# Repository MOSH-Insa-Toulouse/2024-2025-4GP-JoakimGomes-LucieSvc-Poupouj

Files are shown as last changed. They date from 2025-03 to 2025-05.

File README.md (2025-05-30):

<!DOCTYPE html>
<html lang="fr">
<head>
  <meta charset="UTF-8">
</head>

<body>

# 2024-2025-4GP-JoakimGomes-LucieSvc-Poupouj
## Développement d'un capteur low-tech à base de Graphite : de la conception au test

### Sommaire
<hr/>
<ul>
<li> <a href="#Introduction">Introduction </a></li>
<li> <a href="#Livrables">Livrables </a></li>
<li> <a href="#Matériel à disposition">Matériel à disposition </a></li>
<li> <a href="#Simulation électronique sur LTSpice">Simulation électronique sur LTSpice </a></li>
<li> <a href="#Design du PCB avec KiCad">Design du PCB avec KiCad </a></li>
<li> <a href="#Réalisation du Shield">Réalisation du Shield </a></li>
<li> <a href="#Développement du code Arduino">Développement du code Arduino </a></li>
<li> <a href="#Développement de l'application mobile APK avec MIT App Inventor">Développement de l'application mobile APK avec MIT App Inventor </a></li>
<li> <a href="#Banc de test">Banc de test </a></li>
<li> <a href="#Datasheet">Datasheet </a></li>
<li> <a href="#Conclusion">Conclusion </a></li>
<li> <a href="#Contact">Contact </a></li>
</ul>

<h2 id="Introduction">Introduction</h2>

<p>L'UF "du capteur au banc de test" a pour objectif de concevoir un capteur low-tech et de pouvoir ensuite le tester afin de le comparer avec un capteur commercial. Le capteur est à base de graphite, que l'on retrouve notamment dans nos crayons à papier. Son développement est issu de l'article scientifique <i>"Pencil Drawn Strain Gauges and Chemiresistors on Paper"</i>(Cheng-Wei Lin*, Zhibo Zhao*, Jaemyung Kim & Jiaxing Huang). Concevoir ce capteur est relativement simple : on applique à l'aide d'un crayon, du graphite sur un morceau de papier. Les couches de graphite déposées sur le papier agissent comme un conducteur électrique qui, lorsqu'on déforme le papier, a une conductivité (et donc une résistance) qui varie. Cela s'explique par le fait que  le nombre de chaînes de particules de graphite connectées varie selon le type de déformation. En tension, il y a moins de chaines et ces dernières sont plus courtes. C'est le contraire en compression avec des chaines plus proches, laissant ainsi mieux passer le courant.</p>

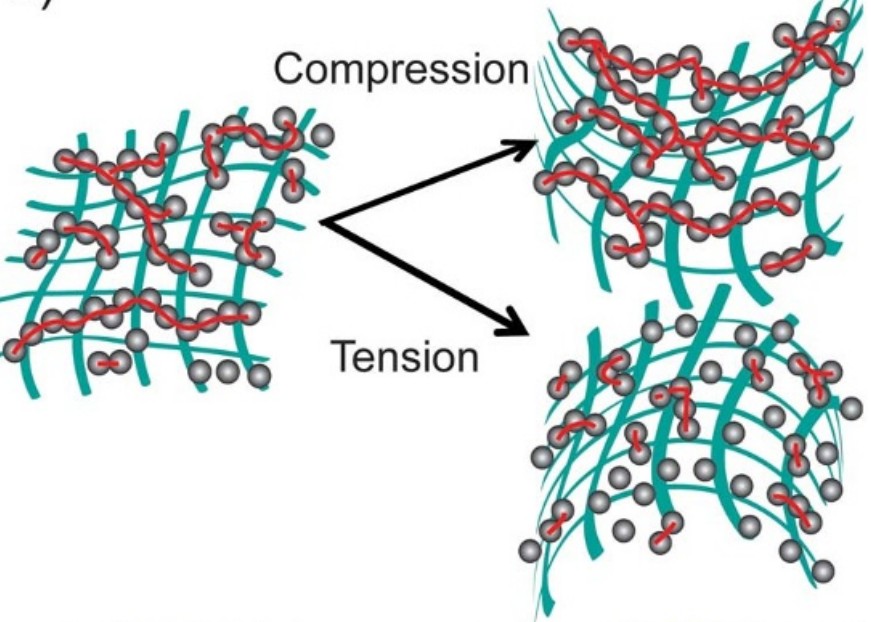
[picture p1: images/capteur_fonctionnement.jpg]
Fonctionnement du capteur


<i>Figure 1 : Image issue de l'article "Pencil Drawn Strain Gauges and Chemiresistors on Paper" qui explique les déformations des chaines sous compression et tension</i>

<h2 id="Livrables">Livrables</h2>
<p>Les livrables de ce projet sont les suivants:</p>
<ul>
<li>Un schield PCB connecté à une carte Arduino UNO et contenant divers éléments:
<ul>
<li>Notre capteur de contrainte Low-tech</li>
<li>Un capteur de flexion commercial</li>
<li>Un amplificateur dont on pourra modifier le gain grâce à un potentiomètre pour le traitement du signal</li>
<li>Un écran OLED pour afficher les données du capteur</li>
<li>Un module Bluetooth permettant la communication avec un téléphone portable</li>
<li>Un encodeur rotatoire pour naviguer dans le menu de l'écran OLED</li>

</ul>
</li></br>
<li>
Le code Arduino qui permet de faire fonctionner tout le système : la communication Bluetooth, la gestion de l'écran OLED avec affichage des données, l'utilisation des deux capteurs de contrainte, la navigation dans le menu de l'écran OLED grâce à l'encodeur rotatoire, la modification du gain grâce au potentiomètre digital.
</li></br>
<li>
L'application Android developpée sur MIT App Inventor, permettant de visualiser les données directement sur son téléphone grâce à la communication Bluetooth.
</li></br>
<li>
Une datasheet pour le capteur en graphite détaillant ses performances et caractéristiques techniques.
</li></br>
</ul>

<h2 id="Matériel à disposition">Matériel à disposition</h2>
<p>Voici la liste du matériel nécessaire pour concevoir le système ci-dessus:</p>
<ul>
<li>Résistances: une résistance de 1kΩ, une résistance de 10kΩ, deux résistances de 100 kΩ, une résistance de 47kΩ pour le Flex sensor commercial et enfin un potentiomètre digital MCP41050</li>
<li>Capacités: trois capacités de 100 nF et une capacité de 1 µF</li>
<li>Un Arduino Uno</li>
<li>Un capteur graphite fait à partir d'un support papier et d'un crayon</li>
<li>Un Flex Sensor commercial</li>
<li>Un encodeur rotatoire Keyes KY-040</li>
<li>Un écran OLED 128x64</li>
<li>Un module Bluetooth HC-05</li>
<li>Un amplificateur opérationnel LTC1050</li>
</ul>

<h2 id="Simulation électronique sur LTSpice">Simulation électronique sur LTSpice</h2>
<p>Les valeurs de résistance de notre capteur graphite sont très élevées, de l'odre du MΩ. Afin de pouvoir les mesurer correctement, il est nécessaire d’amplifier le signal avant acquisition. Le courant mesuré après application d'une tension de 5V est donc très faible. Il est donc nécessaire d'amplifier le signal avant son acquisition</p>
<p>Nous avons donc simulé un montage amplificateur transimpédance sur LTspice pour l'optimiser au mieux pour notre capteur : </p>

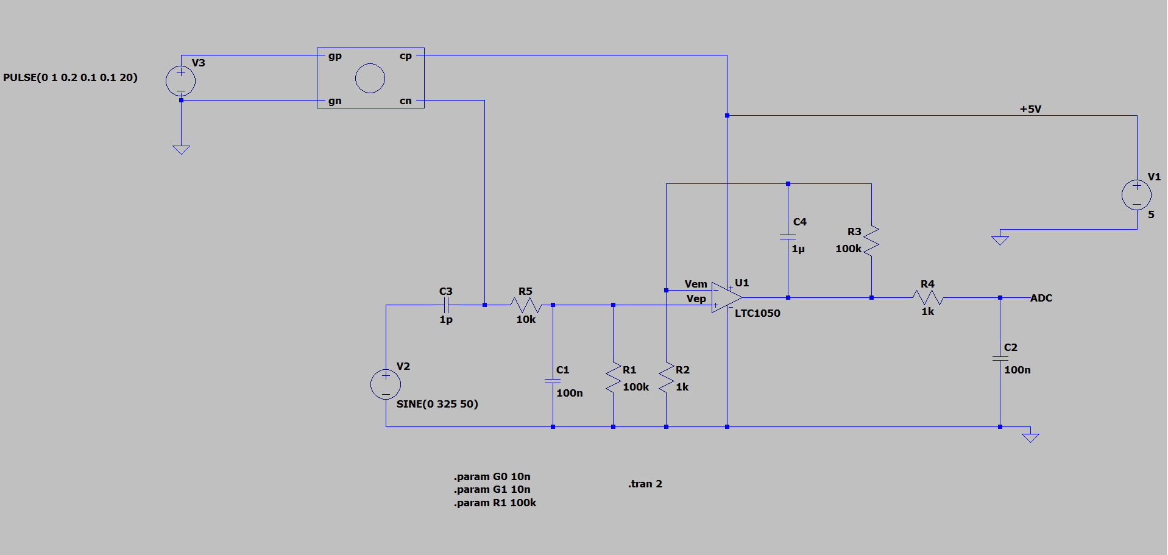
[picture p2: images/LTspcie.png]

<i>Figure 3 : Schéma de notre montage amplificateur sur LTSpice</i>
<p>Ce montage permet d'amplifier le signal du capteur à l'aide de l'amplificateur LTC1050, puis de le filtrer. Ce dernier est divisé en 3 pour limiter le bruit  :</p>
<ul>
<li> R5 et C1 : possède une fréquence de coupure de 16Hz et permet d'atténuer les bruits présents sur le signal d’entrée</li>
<li> R3 et C4 en association avec l’AOP : filtre passe-bas avec une fréquence de coupure de 1,6 Hz, qui permet de filtrer le 50 Hz du réseau électrique</li>
<li> R4 et C2 : possède une fréquence de coupure de 1,6 kHz et permet de filtrer les bruits parasites engendrés par le traitement du signal</li>
</ul>
<p>La tension mesurée, V_ADC, permet ainsi de remonter à la valeur de résistance du graphite mesurée par le capteur, R_capteur , grâce à la formule : </p>
<p>R_capteur=R1*(1+R3/R_pot)*Vcc/V_ADC-R1-R5</p>

<h2 id="Design du PCB avec KiCad">Design du PCB avec KiCad</h2>
<p>La conception du PCB s'est faite à partir du logiciel KiCad 9.0</p>
<p>Nous avons dans un premier temps reproduit le schéma électrique du système sur l'éditeur de Schématique. Il a fallu créer certains composants et récupérer d'autres dans les librairies de symboles (résistances et capacités notamment). Nous avons associé à chaque composant une empreinte et un modèle 3D. On peut alors effectuer l'ensemble des connexions entre les composants et l'Arduino via l'éditeur de Schématique.</p>

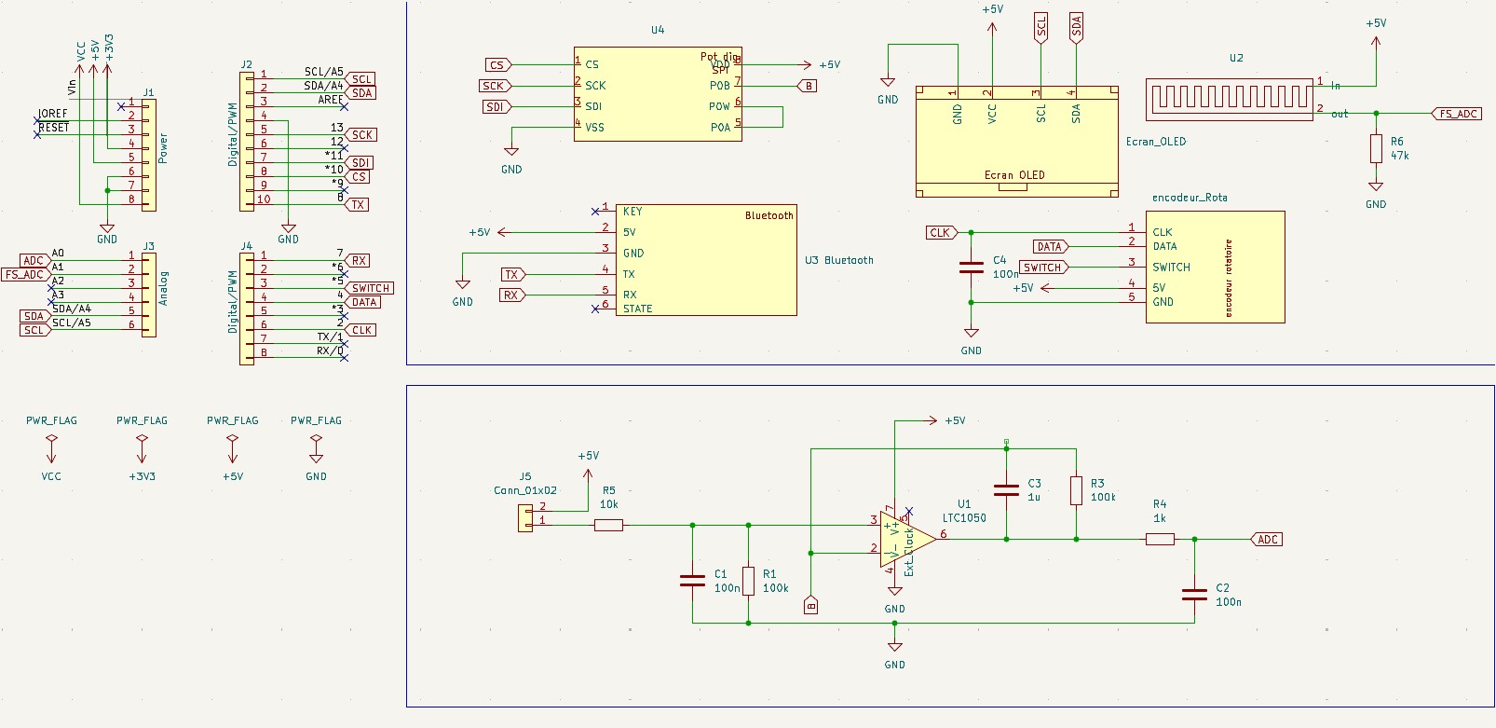
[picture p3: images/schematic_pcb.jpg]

<i>Figure 4 : ensemble du fichier Schématique sous KiCad 9.0</i>

<p>Une fois le schéma électrique terminé, il faut placer les composants sur le PCB grâce à l'éditeur de PCB. L'objectif est de placer les composants judicieusement pour respecter les contraintes imposées, notamment éviter les vias, vérifier que les composants ne se superposent pas physiquement, respecter les dimensions des pistes et l'isolation.</p>

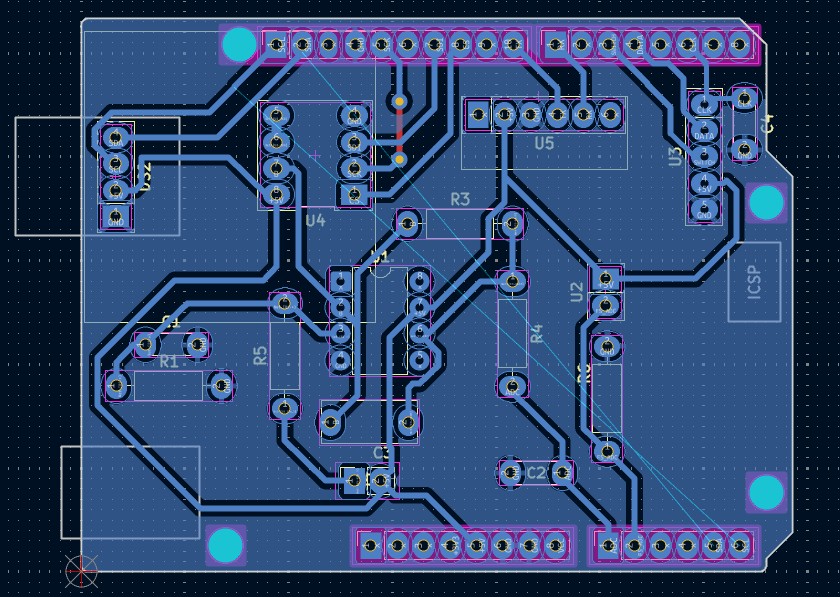
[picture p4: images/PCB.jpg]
Disposition des composants sur le PCB


<i>Figure 5 : Disposition des composants sur l'éditeur de PCB</i>

<p>Et voici la visualisation 3D de notre PCB avec tous les composants (l'amplificateur est sous l'écran OLED).</p>

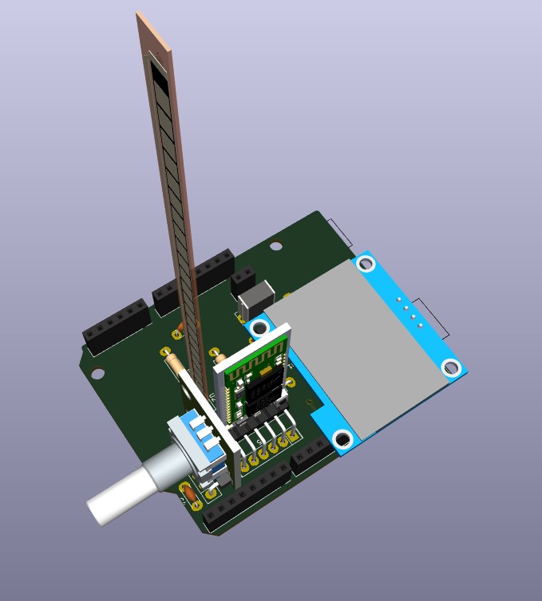
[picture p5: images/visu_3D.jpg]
visualisation 3D
</br>
<i>Figure 6 : Visualisation 3D du PCB et composants</i>

<h2 id="Réalisation du Shield">Réalisation du Shield</h2>
<p>Une fois la conception du PCB sur KiCad terminée, nous avons pu passer à la réalisation physique de ce PCB. 
La première étape essentielle a consisté en la vérification du schéma du circuit imprimé (PCB) à l’aide du logiciel KiCad, afin de s’assurer de sa conformité avant toute fabrication. Une fois cette vérification effectuée, le masque de gravure du PCB a été généré à partir du même logiciel.
Ensuite, a fabrication a débuté par l’insolation UV d’une plaque d’époxy recouverte d’une fine couche de cuivre et d’un film photosensible. Cette exposition à la lumière permet de durcir les zones du film correspondant aux futures pistes du circuit. La plaque a ensuite été plongée dans un révélateur, ce qui a permis de dissoudre la résine restée non exposée à la lumière. La gravure des pistes a ensuite été réalisée par immersion de la plaque dans une solution de perchlorure de fer, qui attaque le cuivre non protégé par la résine insolée. Enfin, un nettoyage à l’acétone a permis de retirer les résidus de résine, révélant ainsi les pistes de cuivre définitives du circuit imprimé.
L’ensemble de ces étapes de fabrication a été réalisé par Cathy Crouzet.

Maintenant que toutes ces étapes ont été effectué, nous allons procéder au montage du capteur. Dans un premier temps, nous avons percé tous les trous afin de pouvoir souder tous les supports des composants sur la PCB. Ensuite, nous pouvons donc souder tous les supports des composants sur la PCB (cf Figure 7). Pour finir, il suffit de simplement mettre les composants sur leur support. Notre capteur est enfin prêt à être utilisé ! (cf Figure 8) </p>

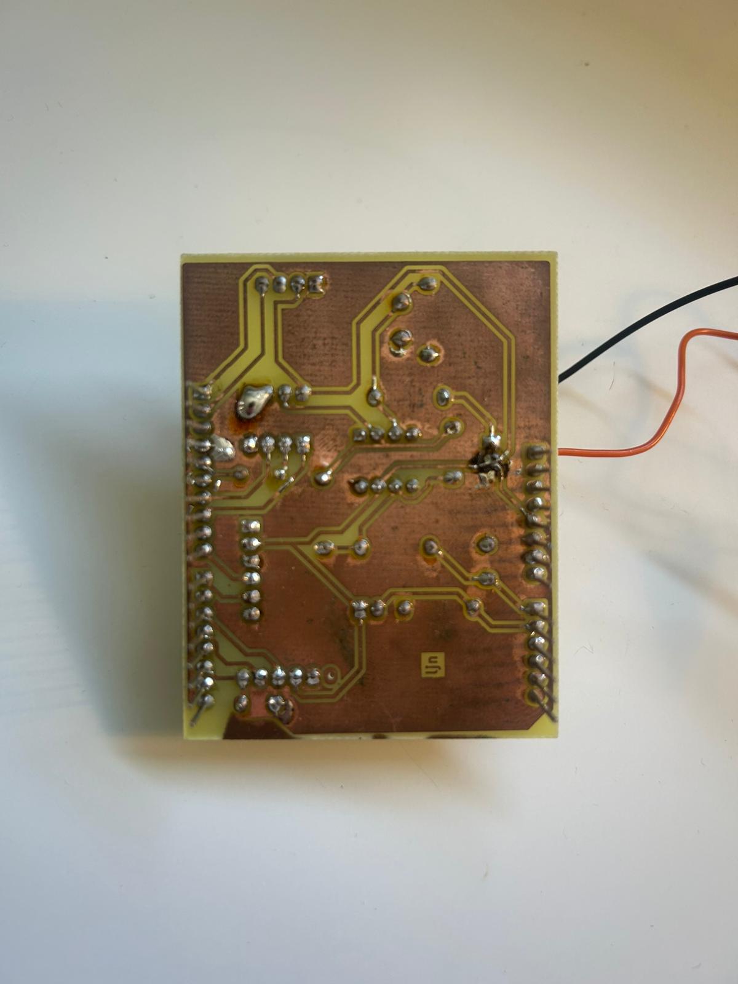
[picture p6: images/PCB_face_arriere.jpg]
visualisation PCB_face_arriere
</br>
<i>Figure  7: Visualisation de la face arrière de la PCB, c'est à dire les soudures.</i>

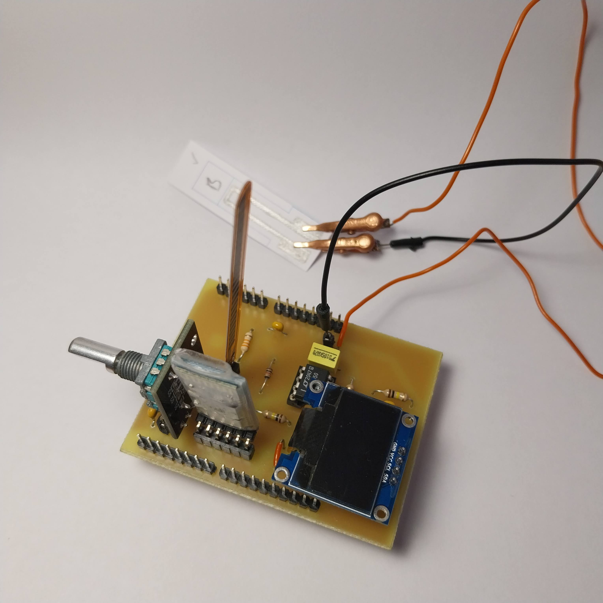
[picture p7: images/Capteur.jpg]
visualisation PCB_face_avant
</br>
<i>Figure  8: Visualisation de la face avant de la PCB, c'est à dire les composants</i>

<h2 id="Développement du code Arduino">Développement du code Arduino</h2>
<p>Une fois la réalisation physique de notre plaque PCB effectuée, il faut à présent développer le code Arduino. Vous pouvez voir notre code sur le github dans la partie "Code Arduino" : https://github.com/MOSH-Insa-Toulouse/2024-2025-4GP-JoakimGomes-LucieSvc-Poupouj/blob/main/Code_Arduino/Capteur_graphite.ino</p>

<h2 id="Développement de l'application mobile APK avec MIT App Inventor">Développement de l'application mobile APK avec MIT App Inventor</h2>
<p>En même temps que la réalisation du code arduino, nous avons développé une application mobile APK avec MIT App Inventor. Cette application permet d'effectuer les mesures du capteur graphite, notamment obtenir un graphe  de la résistance en fonction de la tension/compression en temps réel. L'application connecte donc via le module bluetooth notre capteur avec un téléphone android.</p>

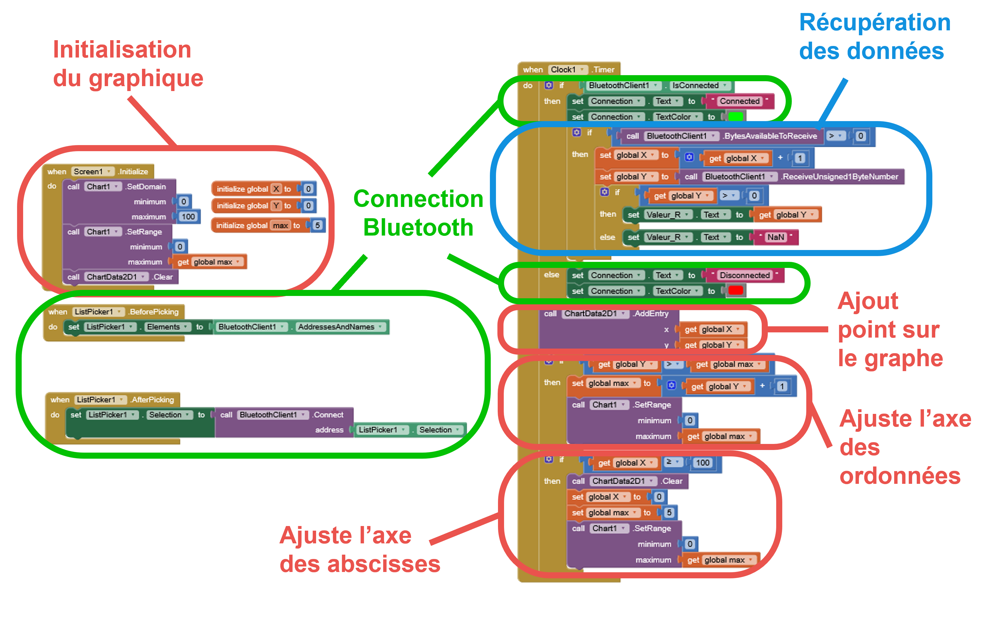
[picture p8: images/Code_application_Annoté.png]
</br>
<i>Figure  9: Visualisation du code de l'application</i>

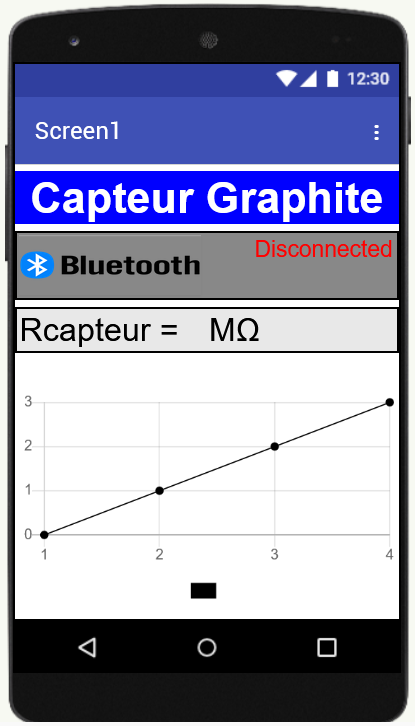
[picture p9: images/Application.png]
</br>
<i>Figure  10: Visualisation de l'interface de l'application</i>

<h2 id="Banc de test">Banc de test</h2>
<p>Maintenant que notre plaque PCB est réalisé virtuellement, puis physiquement, et que notre code arduino ainsi que notre application fonctionnent correctement, nous pouvons réaliser le banc de test. L'objectif est de calculer la valeur de la résistance du capteur graphite pour différentes valeurs de déformation. Pour cela nous avons utilisé un support avec des cylindres de rayons différents (1,5 cm, 2 cm, ..., 4cm). </p>
<p>Notre papier de test ayant une épaisseur e = 0,214mm nous pouvons calculer la déformation engendrée par chacun des rayons de courbure avec la formule : ϵ = e/2r</p>
<p>Nous avons donc effectué des mesures en Tension et en Compression pour des crayons de duretés différentes (2H, B, 3B, 6B) avec une valeur de potentiomètre 1 960 Ω.</p>
<p>En traçant la courbe ΔR/R0 en fonction de la déformation, la théorie nous dit que nous devons avoir une relation linéaire entre les 2. Nous avons donc tracé une droite de régression linéaire passant par 0 pour chacune des courbes et trouvons les résultats suivants :</p>

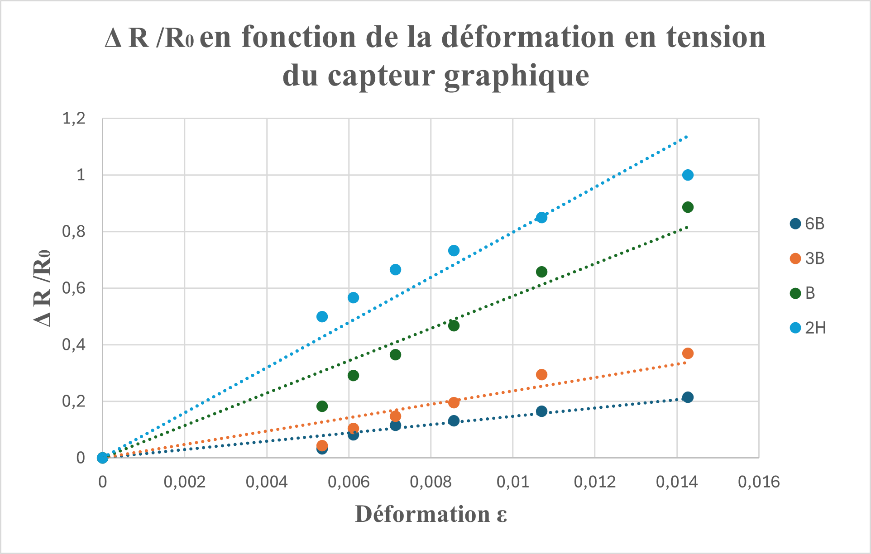
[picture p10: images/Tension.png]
</br>
<i>Figure  11: Courbes de ΔR/R0 en fonction de la déformation en Tension</i>

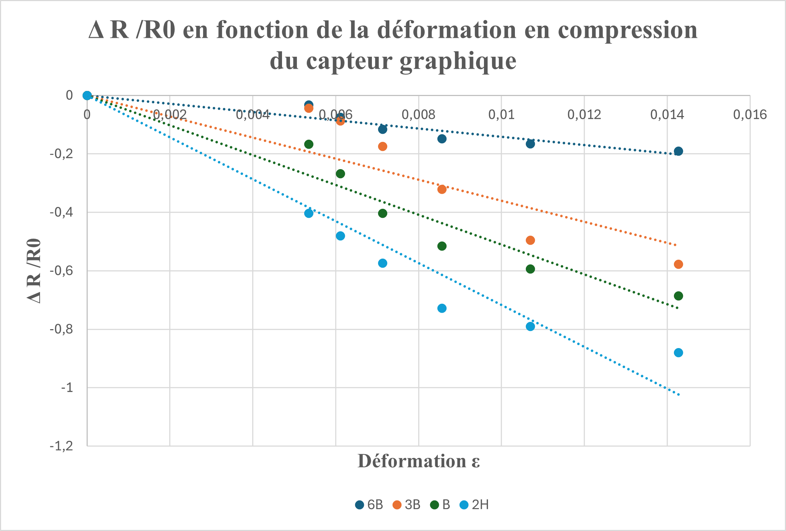
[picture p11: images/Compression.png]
</br>
<i>Figure  12: Courbes de ΔR/R0 en fonction de la déformation en Compression</i>

<p>Comme prédit par la théorie, nous pourvons observer que en Tension la résistance augmente avec la déformation, alors qu'en Compression elle diminue. De plus, plus le crayon est sec (ex : 2H) plus la pente est élevée. Nous remarquons cependant que pour le crayons 2H semble perdre en précision quand la déformation est élevée (pente de la courbe diminue). Cela peut s'expliquer car il y a très peu de chaines de particules permettant la déformation.</p>

<h2 id="Datasheet">Datasheet</h2>
<p>Le contenu de notre Datasheet se trouve avec le lien suivant : https://github.com/MOSH-Insa-Toulouse/2024-2025-4GP-JoakimGomes-LucieSvc-Poupouj/blob/main/Datasheet_Capteur_Graphite.docx</p>

<h2 id="Conclusion">Conclusion</h2>
<p>Pour conclure, ce projet capteur a été très enrichissant sur plusieurs aspect. Nous avons pu développer de nombreuses compétences, surtout sur un aspect technique. Le plus passionant au sein de ce projet étant la réalisation du projet de A à Z. En effet, nous avons commencé par la théorie, puis la pratique avec la fabrication du capteur, jusqu'au résultat final et une analyse de mesure. C'est donc un projet très complet d'un point de vue pédagogique. 

En ce qui concerne le capteur graphite réalisé, il fonctionne et est utilisable. En revanche, il manque encore grandement de précision. En effet, il n'est pas assez "stable" et "constant" lors de son utilisation. Par exemple, il ne donne pas exactement les mêmes résultats après chaque mesure réalisée de manière identique. Ceci est sûrement dû au manque de matériel de mesure précis. Effectivement, faire les mesures "à la main" n'est pas très bon d'un point de vue rigueur et scientifique. Le capteur manque parfois de graphite ou alors la flexion ou compression n'est pas exactement bien réalisée... De plus on peut voir la limite d'utilisation au crayon 2H (cf datasheet), en dessous duquel (donc crayon moins gras), il n'est plus possible d'être mesuré. Il ne peut donc pas encore être industrialisable. Cependant, nous pouvons quand même noté que le 2H fonctionne contrairement aux études menées dans "Pencil Drawn Strain Gauges and Chemiresistors on Paper"(Cheng-Wei Lin*, Zhibo Zhao*, Jaemyung Kim & Jiaxing Huang). Nous observons notamment une bonne réponse linéaire jusqu'à une déformation de 0.007 en tension.</p>

<h2 id="Contact">Contact</h2>
<p>Pour tout besoin d'informations complémentaires, veuillez nous contacter via les adresses mails INSA suivantes :</p>
<ul>
<li>Joakim GOMES CORREIA : gomescor@insa-toulouse.fr</li>
<li>Lucie SAUVIAC : sauviac@insa-toulouse.fr</li>
<li>Nicolas POUJOL : npoujol@insa-toulouse.fr</li>
</ul>

</body>
</html>

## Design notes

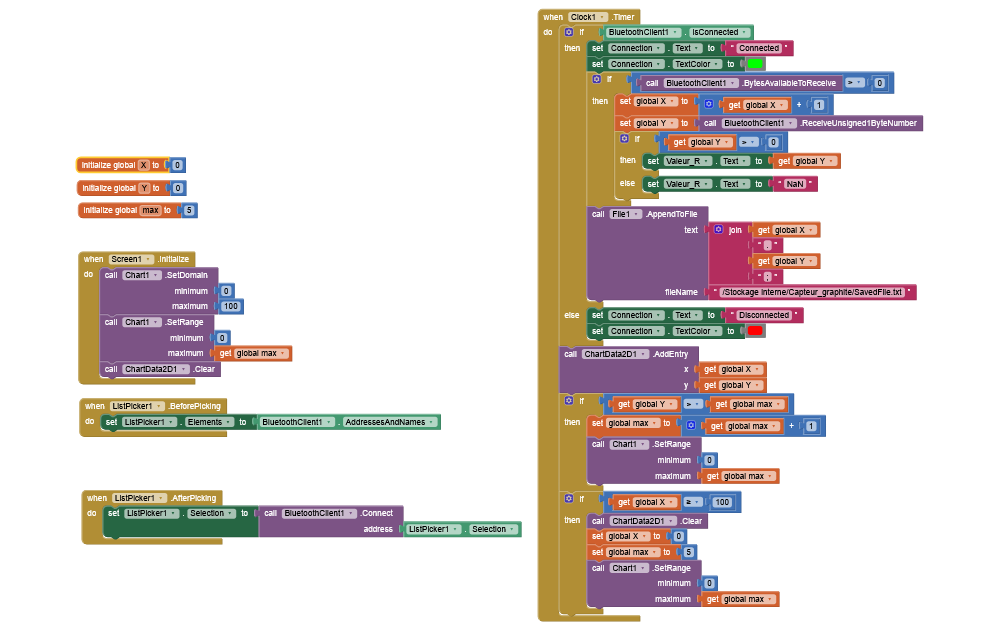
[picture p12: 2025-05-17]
images/Code_application.png

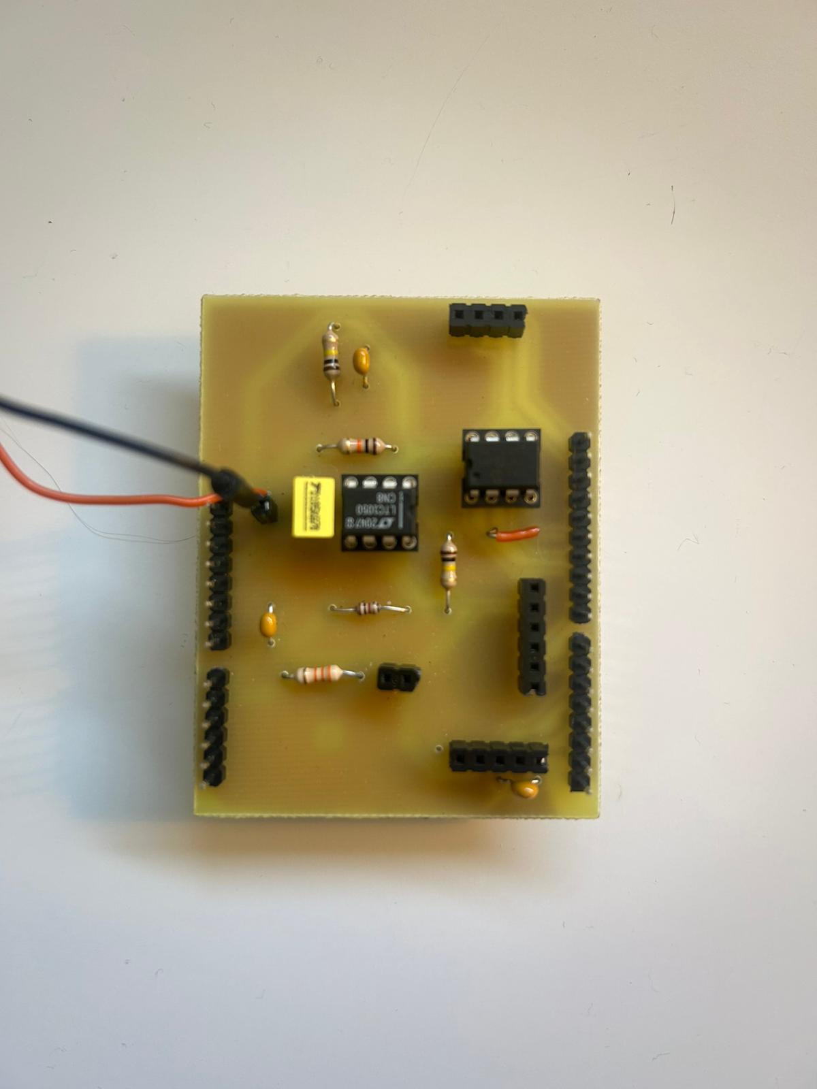
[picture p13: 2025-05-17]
images/PCB_face_avant.jpg

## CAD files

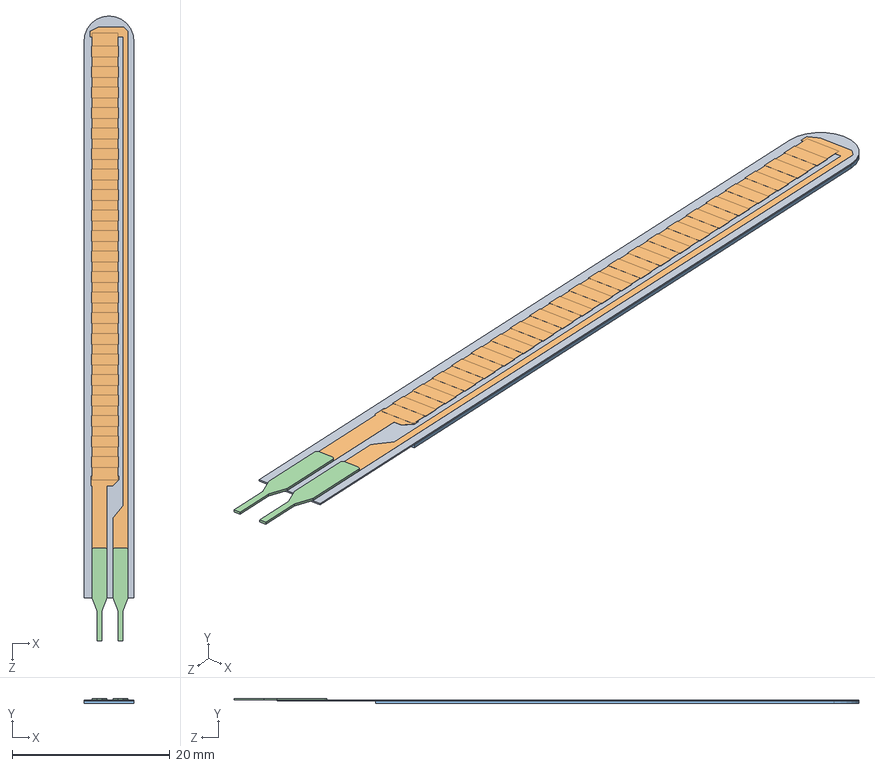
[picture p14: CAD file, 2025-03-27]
Shield/FlexSensor.SLDASM
6.35 x 0.648 x 79.3 mm
PlasticFilm
Flex_Sensor_Circuit
Plastic_Stiffner
GoldProngTerminal x 2

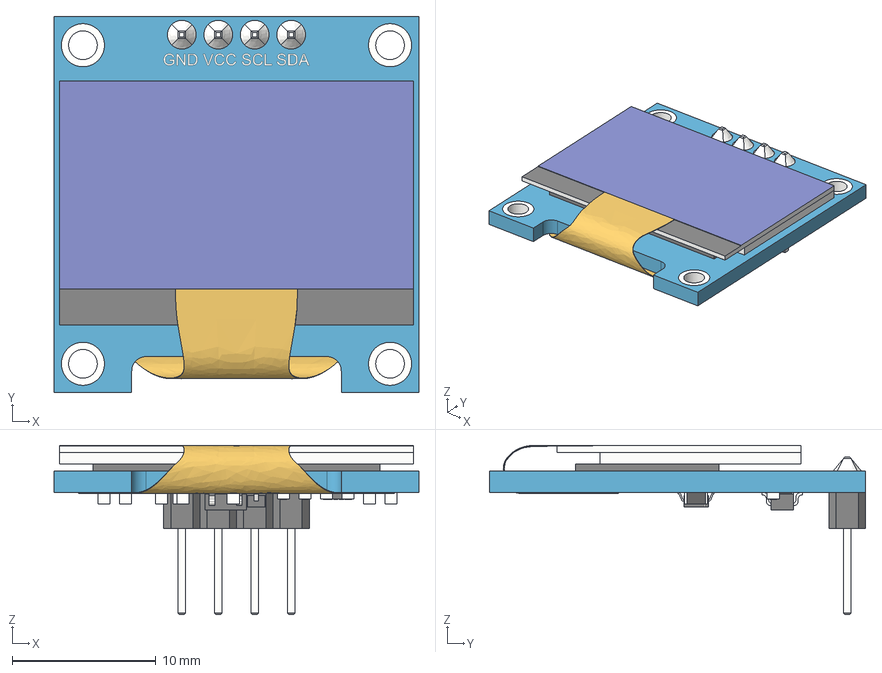
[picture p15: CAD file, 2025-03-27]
Shield/SSD1306_OLED_Display(128x64).step
25.4 x 26.2 x 11.8 mm
board
screen
pin_header
soldering
smd_capacitor
smd_capacitor (1)
914_smd_resistor
472_smd_resistor x 3
t4_smd_diode
smd_capacitor (2)
smd_capacitor (3)
smd_capacitor (4)
smd_capacitor (5)
smd_capacitor (6)
472_smd_resistor (1)
SOT-23_XC6206 v3
smd_capacitor (7)
flat_cable

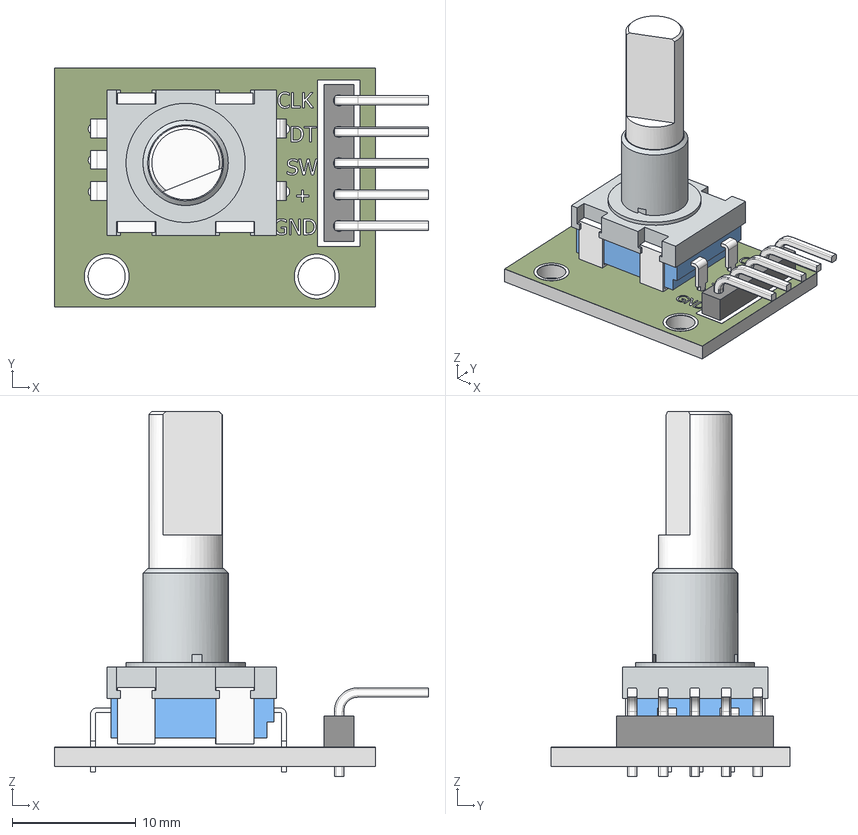
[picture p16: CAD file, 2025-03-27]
Shield/rotary+encoder_17mm_hole_spc.stp
30.3 x 19.3 x 29.6 mm
pcb
mtg flange
body_encoder
5 pin header
90d pin_header x 5
decal_encoder
pins_encoder body_2 x 5
shaft_encoder

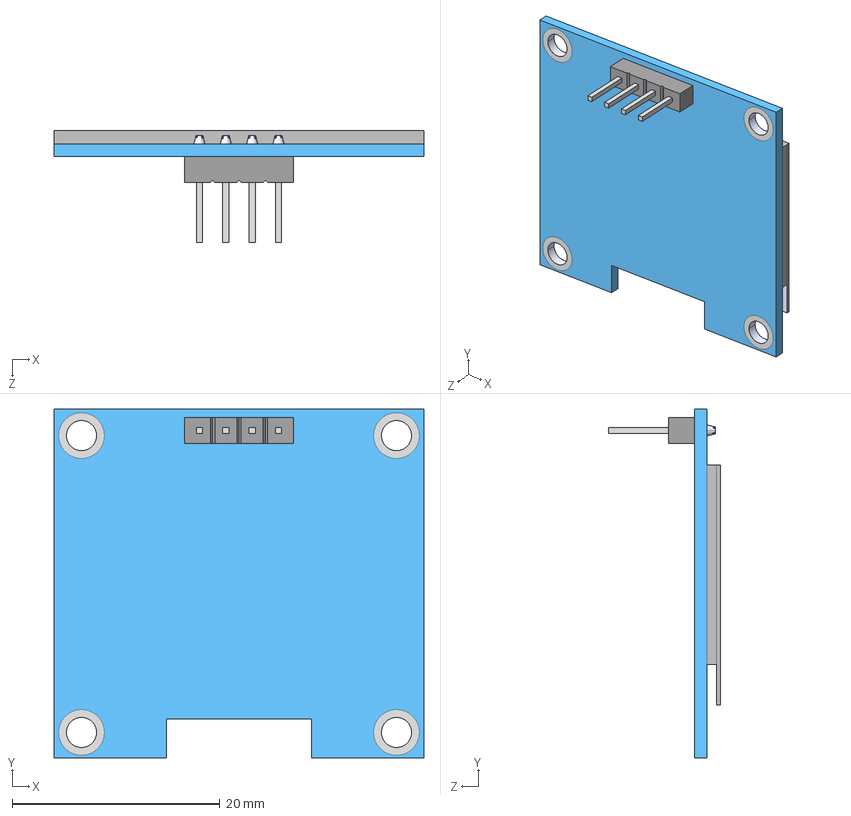
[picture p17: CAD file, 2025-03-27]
Shield/1 3 OLED ICC .STEP
35.7 x 33.6 x 10.8 mm

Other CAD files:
Shield/rotary+encoder_14mm_hole_spc.stp

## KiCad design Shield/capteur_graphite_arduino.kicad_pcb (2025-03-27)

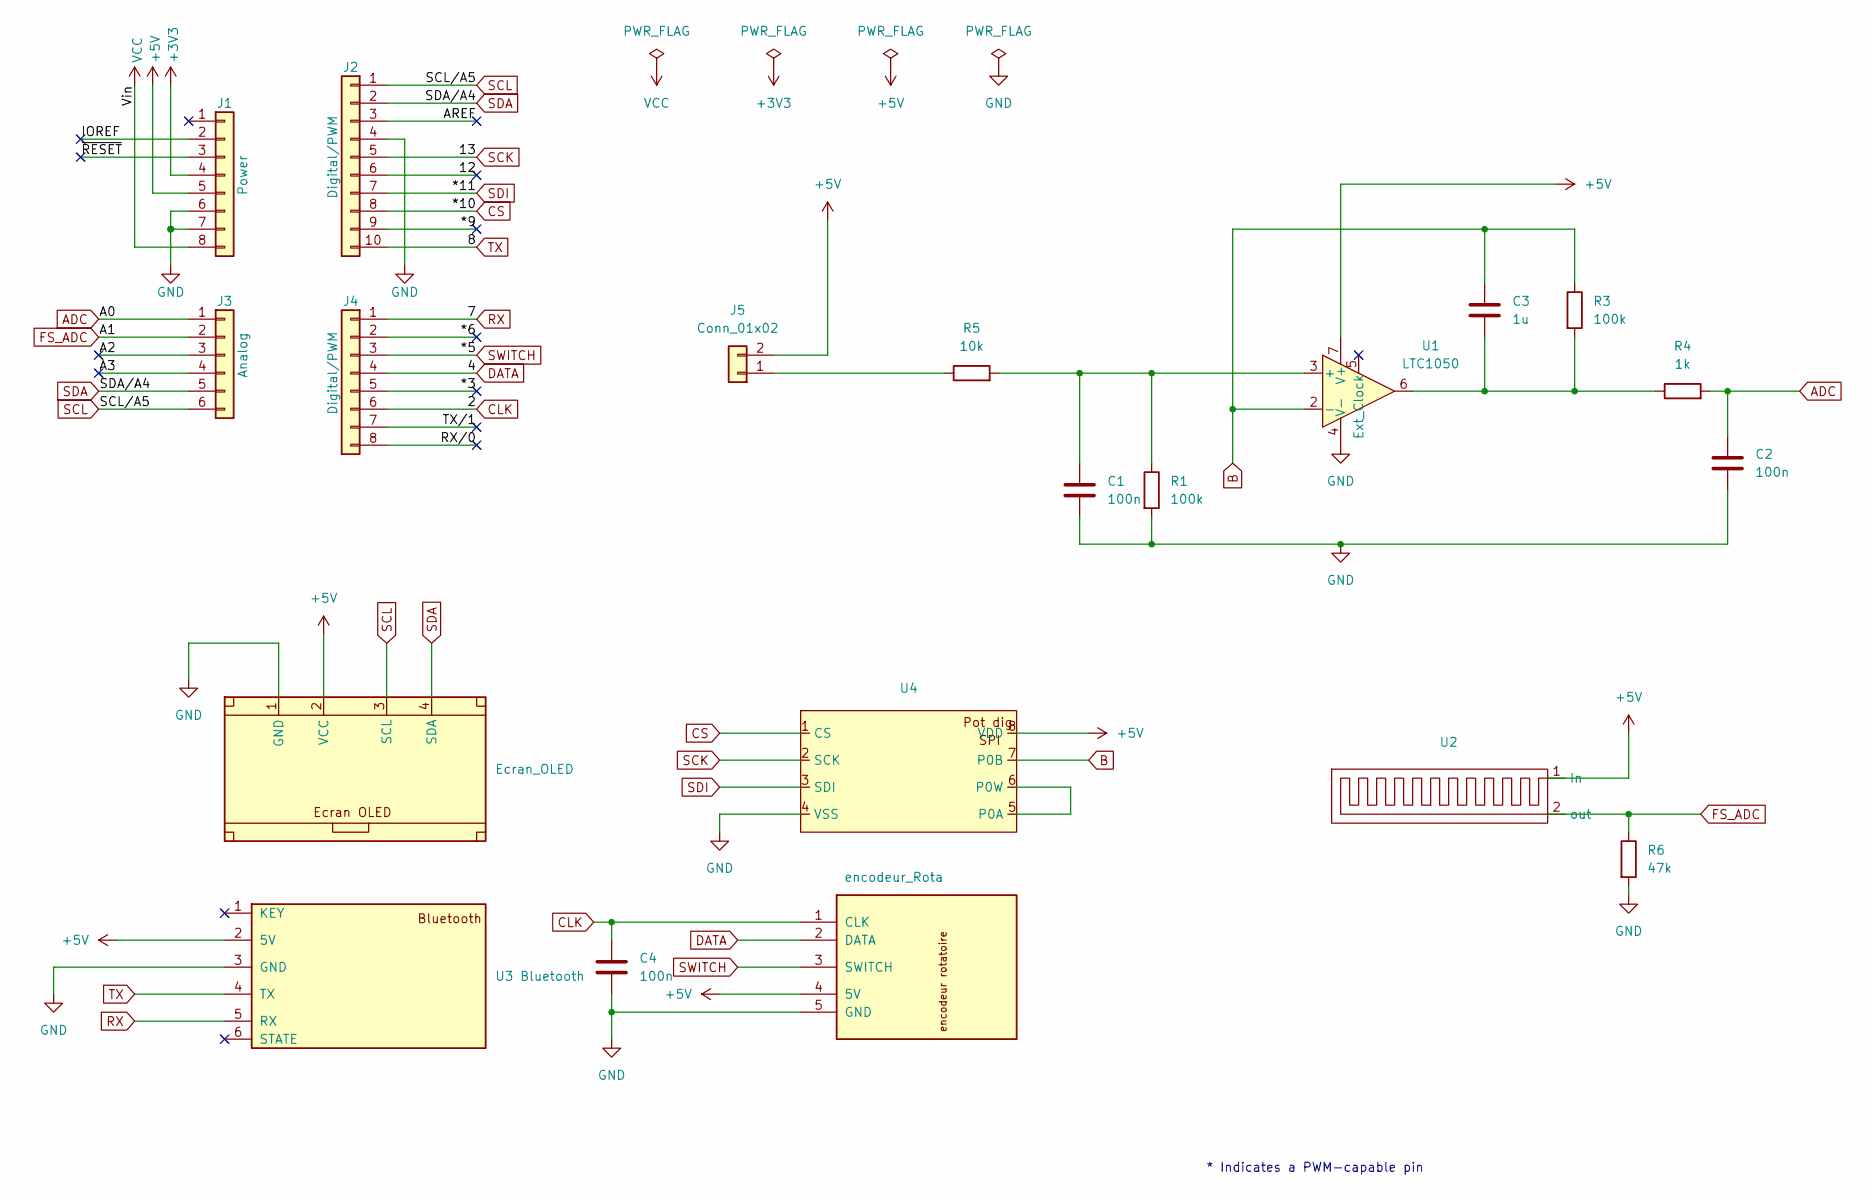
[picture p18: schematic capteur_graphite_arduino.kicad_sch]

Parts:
C1, C2, C4: 100n; C_Disc_D4.3mm_W1.9mm_P5.00mm
C3: 1u; C_Rect_L9.0mm_W3.9mm_P7.50mm_MKT
DS2: Ecran_OLED; OLED
J1: Power; PinSocket_1x08_P2.54mm_Vertical
J2: Digital/PWM; PinSocket_1x10_P2.54mm_Vertical
J3: Analog; PinSocket_1x06_P2.54mm_Vertical
J4: Digital/PWM; PinSocket_1x08_P2.54mm_Vertical
J5: Conn_01x02; PinSocket_1x02_P2.54mm_Vertical
R1, R3: 100k; R_Axial_DIN0207_L6.3mm_D2.5mm_P10.16mm_Horizontal
R4: 1k; R_Axial_DIN0207_L6.3mm_D2.5mm_P10.16mm_Horizontal
R5: 10k; R_Axial_DIN0207_L6.3mm_D2.5mm_P10.16mm_Horizontal
R6: 47k; R_Axial_DIN0207_L6.3mm_D2.5mm_P10.16mm_Horizontal
U1: LTC1050; DIP-8_W7.62mm
U2: flex_sensor
U3: encodeur_Rota; rotencodeur
U4: pot_dig
U5: U3 Bluetooth; Bluetooth

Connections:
+3V3: J1.4
+5V: DS2.2 (VCC), J1.5, J5.2, U1.7 (V+), U2.1 (In), U3.4 (5V), U4.8 (VDD), U5.2 (5V)
/12: J2.6
/*3: J4.5
/*6: J4.2
/*9: J2.9
/A2: J3.3
/A3: J3.4
/AREF: J2.3
/IOREF: J1.2
/RX/0: J4.8
/TX/1: J4.7
/~RESET: J1.3
ADC: C2.1, J3.1, R4.2
B: C3.1, R3.1, U1.2 (-), U4.7 (P0B)
CLK: C4.1, J4.6, U3.1 (CLK)
CS: J2.8, U4.1 (CS)
DATA: J4.4, U3.2 (DATA)
FS_ADC: J3.2, R6.1, U2.2 (out)
GND: C1.2, C2.2, C4.2, DS2.1 (GND), J1.6, J1.7, J2.4, R1.2, R6.2, U1.4 (V-), U3.5 (GND), U4.4 (VSS), U5.3 (GND)
unnamed: C3.2, R3.2, R4.1, U1.6
unnamed: J5.1, R5.1
unnamed: C1.1, R1.1, R5.2, U1.3 (+)
unnamed: U4.5 (P0A), U4.6 (P0W)
RX: J4.1, U5.5 (RX)
SCK: J2.5, U4.2 (SCK)
SCL: DS2.3 (SCL), J2.1, J3.6
SDA: DS2.4 (SDA), J2.2, J3.5
SDI: J2.7, U4.3 (SDI)
SWITCH: J4.3, U3.3 (SWITCH)
TX: J2.10, U5.4 (TX)
VCC: J1.8

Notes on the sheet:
* Indicates a PWM-capable pin

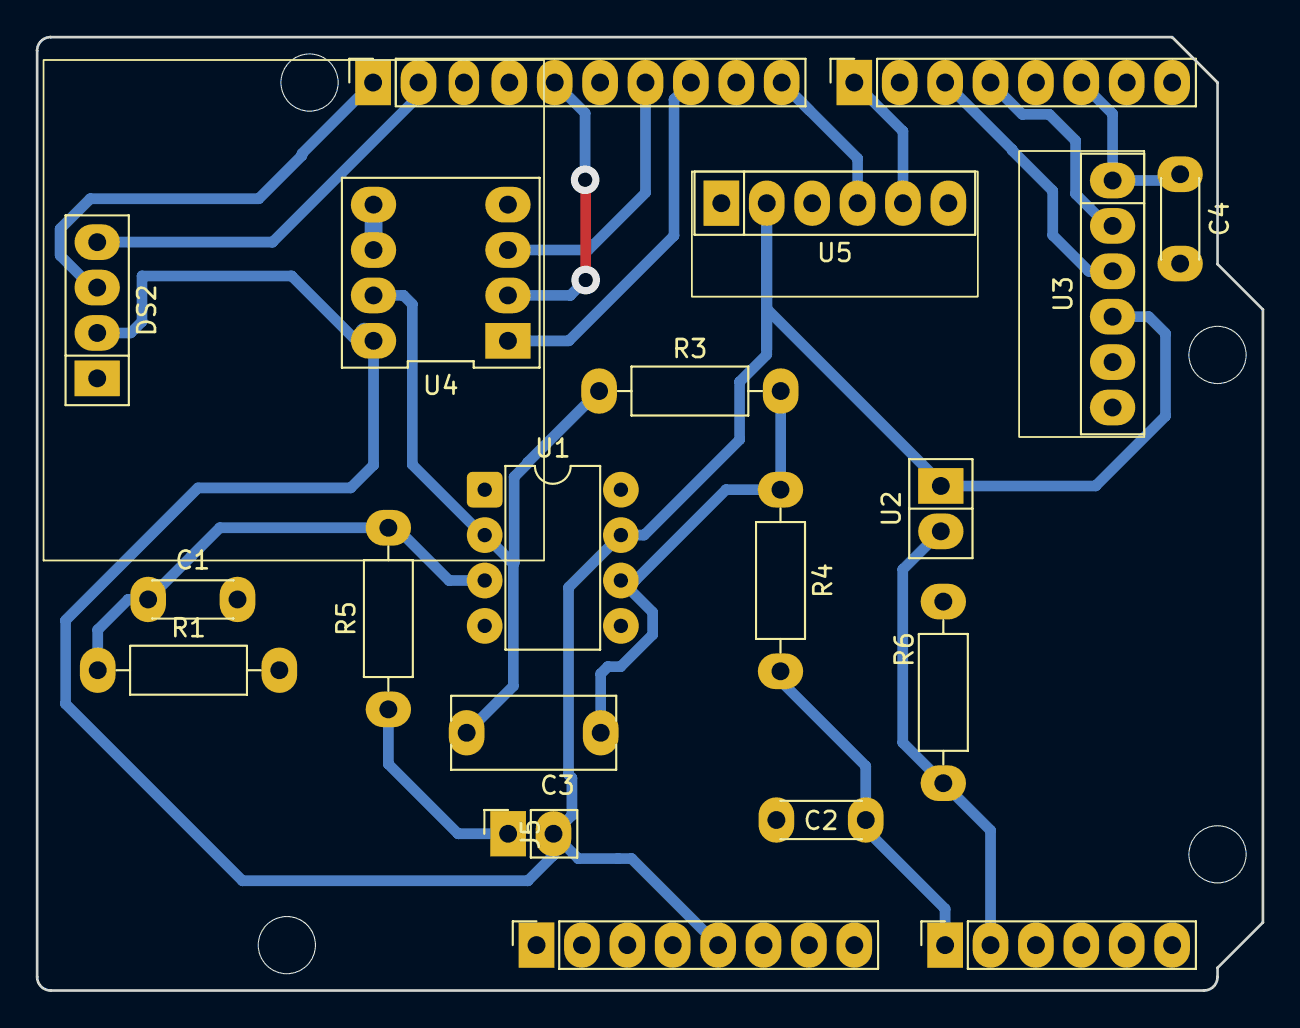
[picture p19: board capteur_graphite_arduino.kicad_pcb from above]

Board: 2 copper layers, 68.6 x 53.3 mm, 24 parts (0 on the bottom side), 19 nets.

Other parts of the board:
MH1, MH2, MH3, MH4: MountingHole_3.2mm

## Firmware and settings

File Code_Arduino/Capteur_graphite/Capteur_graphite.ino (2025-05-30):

// Définition des pins
#define encoder0PinA  2  // CLK Output A
#define encoder0PinB  4  // DT Output B
#define Switch 5  // Bouton de l'encodeur

#include <Adafruit_SSD1306.h>
#include <SPI.h>

const byte csPin = 10;
const int maxPositions = 256;
const long rAB = 50000.0;
const byte rWiper = 125;
const byte pot0 = 0x11;
const byte pot0Shutdown = 0x21;
int potValue = 10;  // Valeur du potentiomètre digital (0 à 255)
bool editingPotValue = false;  // Indique si on est en train de régler la valeur
float resistanceWB;

#define OLED_WIDTH 128
#define OLED_HEIGHT 64
#define OLED_RESET -1
#define OLED_I2C_ADDR 0x3C

Adafruit_SSD1306 ecranOLED(OLED_WIDTH, OLED_HEIGHT, &Wire, OLED_RESET);

// Variables globales
volatile int encoder0Pos = 0;
volatile bool encoderChanged = false;

int menuState = 0;  // 0 = Menu principal, 1 = Config, 2 = Mesure, 3 = Flex, 4 = Graphite
int selection = 0;  // Position de sélection (0, 1 ou 2)

bool lastButtonState = HIGH;
bool buttonPressed = false;

uint8_t ValeurResbitAppli;

//Bluetooth
#include <SoftwareSerial.h>
#define RX 8  // Broche RX du module Bluetooth
#define TX 7  // Broche TX du module Bluetooth
#define ADC A0  // Broche de lecture de la résistance
SoftwareSerial bluetooth(RX, TX);  // Création d'un port série logiciel

//FlexSensor
#define FLEX_SENSOR_PIN A1
#define GRAPHITE_SENSOR_PIN A0
#include <Wire.h>
#include <Adafruit_GFX.h>

const float R_DIV = 33000.0;
const float flatresistance = 33000.0;
const float bendresistance = 75000.0;

const float R3 = 100000.0;
const float R1 = 100000.0;
const float R5 = 10000.0;

unsigned long currentTime;



// Potentiomètre digital
#include <SPI.h>
// Note: command byte format xxCCxxPP, CC command, PP pot number (01 if selected) 
#define MCP_NOP 0b00000000
#define MCP_WRITE 0b00010001
#define MCP_SHTDWN 0b00100001
const int ssMCPin = 10; // Define the slave select for the digital pot

void SPIWrite(uint8_t cmd, uint8_t data, uint8_t ssPin) // SPI write the command and data to the MCP IC connected to the ssPin
{
  SPI.beginTransaction(SPISettings(14000000, MSBFIRST, SPI_MODE0)); //https://www.arduino.cc/en/Reference/SPISettings
  
  digitalWrite(ssPin, LOW); // SS pin low to select chip
  
  SPI.transfer(cmd);        // Send command code
  SPI.transfer(data);       // Send associated value
  
  digitalWrite(ssPin, HIGH);// SS pin high to de-select chip
  SPI.endTransaction();
}

void doEncoder();

// === Déclaration de la fonction avant setup ===
void setup() {
  Serial.begin(9600);

  digitalWrite(csPin, HIGH);
  pinMode(csPin, OUTPUT);
  SPI.begin();

  pinMode(encoder0PinA, INPUT);
  pinMode(encoder0PinB, INPUT);
  pinMode(Switch, INPUT_PULLUP);

  attachInterrupt(digitalPinToInterrupt(encoder0PinA), doEncoder, CHANGE);

  if (!ecranOLED.begin(SSD1306_SWITCHCAPVCC, OLED_I2C_ADDR)) {
    while (1);
  }

  afficherMenu();  

  //Bluetooth
  pinMode(RX,INPUT); // On définit le pin Rx en INPUT
  pinMode(TX,OUTPUT); // On définit le pin Tx en OUTPUT
  pinMode(ADC,INPUT); // On définit l'entrée analogique A0 en INPUT
  bluetooth.begin(9600);  // Communication avec le module Bluetooth
                          


  // Pot digital
  pinMode (ssMCPin, OUTPUT); //select pin output
  digitalWrite(ssMCPin, HIGH); //SPI chip disabled
  SPI.begin(); 
  setPotWiper(pot0, potValue);
}

unsigned long lastSendTime = 0;

void loop() {
  // autres traitements ici...
  
  detecterAppuiBouton();

  if (encoderChanged) {
    encoderChanged = false;
    afficherMenu();
  }

  if (menuState == 3) {
    afficherValeurFlex();
  } else if (menuState == 4) {
    afficherValeurGraphite(resistanceWB);
  }
}


void setPotWiper(int addr, int pos) {
  pos = constrain(pos,0,255);
  SPI.beginTransaction(SPISettings(14000000,MSBFIRST, SPI_MODE0));
  digitalWrite(csPin, LOW);
  SPI.transfer(addr);
  SPI.transfer(pos);
  digitalWrite(csPin, HIGH);
  SPIWrite(MCP_WRITE, pos, ssMCPin);  ////
  SPI.endTransaction();

  //Rpot = pos * 50000 / 255;
  //resistanceWB 
  resistanceWB = ( (rAB * pos) / maxPositions ) + rWiper;
  /*Serial.print("Wiper position: ");
  Serial.print(pos);
  Serial.print("Resistance wiper to B: ");
  Serial.print(resistanceWB);
  Serial.println(" ohms");*/
}

void detecterAppuiBouton() {
  bool buttonState = digitalRead(Switch);

  if (buttonState == LOW && lastButtonState == HIGH) {
    delay(50);
    if (digitalRead(Switch) == LOW) {
      buttonPressed = true;
    }
  }

  if (buttonState == HIGH && lastButtonState == LOW) {
    if (buttonPressed) {
      if (menuState == 5) {  
        setPotWiper(pot0, potValue);  // Appliquer la valeur
        Serial.print("Potentiomètre réglé sur: ");
        Serial.println(potValue);
        menuState = 1;  // Retour au menu CONFIG après validation
        selection = 0;  // Réinitialisation de la sélection
        encoderChanged = true;  // Forcer la mise à jour
      } else {
        changerMenu();
      }
      buttonPressed = false;
    }
  }

  lastButtonState = buttonState;
}

void afficherMenu() {
  ecranOLED.clearDisplay();
  ecranOLED.setTextSize(2);

  if (menuState == 0) {  // Menu principal
    afficherOption("Config", 0);
    afficherOption("Mesure", 1);
  } else if (menuState == 1) {  // Sous-menu "Config"
    afficherOption("Regler Pot", 0);
    afficherOption("Retour", 1);
  } else if (menuState == 2) {  // Sous-menu "Mesure"
    afficherOption("Graphite", 0);
    afficherOption("Flex", 1);
    afficherOption("Retour", 2);
  } else if (menuState == 3) {  // Menu du capteur Flex
    afficherOption("Mesurer", 0);
    afficherOption("Retour", 1);
  } else if (menuState == 4) {  // Menu du capteur Graphite
    afficherOption("Mesurer", 0);
    afficherOption("Retour", 1);
  } else if (menuState == 5) {  // Menu de réglage du potentiomètre
    afficherValeurPotentiometre();
  }

  ecranOLED.display();
}

void afficherOption(const char *texte, int position) {
  ecranOLED.setTextSize(1);
  if (selection % 3 == position) {
    ecranOLED.setTextColor(SSD1306_BLACK, SSD1306_WHITE);
  } else {
    ecranOLED.setTextColor(SSD1306_WHITE, SSD1306_BLACK);
  }
  ecranOLED.setCursor(20, 10 + (position * 20));
  ecranOLED.println(texte);
}

void afficherValeurFlex() {
  while (menuState == 3) {  // Reste dans cette boucle tant que l'utilisateur ne sort pas
    ecranOLED.clearDisplay();
    ecranOLED.setTextSize(1);
    ecranOLED.setTextColor(SSD1306_WHITE);

    int VFlexbrute = analogRead(FLEX_SENSOR_PIN);
    float VFlexSensor = ((VFlexbrute) / 1024.0) * 5.0; // Conversion en tension
    float RFlexSensor = R_DIV * (5.0 / VFlexSensor - 1.0);
    float angle = map(RFlexSensor, flatresistance, bendresistance, 0, 90.0);

    ecranOLED.setCursor(10, 0);
    ecranOLED.println("Flex Sensor:");

    ecranOLED.setCursor(10, 20);
    ecranOLED.print(VFlexSensor);
    ecranOLED.println(" V");

    ecranOLED.setCursor(10, 30);
    ecranOLED.print(RFlexSensor);
    ecranOLED.println(" MOhms");

    ecranOLED.setCursor(10, 40);
    ecranOLED.print(angle);
    ecranOLED.println(" degrees");

    ecranOLED.setCursor(10, 50);
    ecranOLED.setTextColor(SSD1306_BLACK, SSD1306_WHITE);
    ecranOLED.println("Retour");

    ecranOLED.display();

    detecterAppuiBouton();  // Vérifie si l'utilisateur appuie sur "Retour"
    delay(200);  // Petite pause pour éviter les rafraîchissements trop rapides
  }
}

void afficherValeurGraphite(float Rpot) {
  while (menuState == 4) {  // Reste dans cette boucle tant que l'utilisateur ne sort pas
    ecranOLED.clearDisplay();
    ecranOLED.setTextSize(1);
    ecranOLED.setTextColor(SSD1306_WHITE);

    float VGraphiteBrute = analogRead(GRAPHITE_SENSOR_PIN);
    float RGraphiteSensor = ((1.0 + R3 / Rpot) * R1 * (1024.0/VGraphiteBrute)) - R1 - R5;
    RGraphiteSensor = RGraphiteSensor/1000000;
    Serial.println("mesure: ");
    Serial.println(VGraphiteBrute);
    float VADC = (float)VGraphiteBrute*5.0/1024.0;
    Serial.println(VADC);
    Serial.println(RGraphiteSensor);
    Serial.println(Rpot);


    ecranOLED.setCursor(10, 0);
    ecranOLED.println("Graphite Sensor:");

    ecranOLED.setCursor(10, 30);
    ecranOLED.print(RGraphiteSensor);
    ecranOLED.println(" MOhms");

    ecranOLED.setCursor(10, 50);
    ecranOLED.setTextColor(SSD1306_BLACK, SSD1306_WHITE);
    ecranOLED.println("Retour");

    ecranOLED.display();

    bluetooth.write(RGraphiteSensor); ////////////////////////////////////////////////////////////////////////////////

    detecterAppuiBouton();  // Vérifie si l'utilisateur appuie sur "Retour"   
    delay(200);  // Petite pause pour éviter les rafraîchissements trop rapides

  /*currentTime = millis();
  // Bluetooth - exécution toutes les 50 ms
  if (currentTime - lastSendTime >= 1000) {
    lastSendTime = currentTime;
    
  }*/

  }
}

void afficherValeurPotentiometre() {
  ecranOLED.clearDisplay();
  ecranOLED.setTextSize(1);
  ecranOLED.setTextColor(SSD1306_WHITE);
    
  ecranOLED.setCursor(10, 10);
  ecranOLED.println("Potentiom.");
    
  ecranOLED.setCursor(10, 30);
  ecranOLED.print("Valeur: ");
  ecranOLED.print(potValue);
    
  ecranOLED.setCursor(10, 50);
  if (selection == 0) {
    ecranOLED.setTextColor(SSD1306_BLACK, SSD1306_WHITE);
  } else {
    ecranOLED.setTextColor(SSD1306_WHITE, SSD1306_BLACK);
  }
  ecranOLED.println("OK");

  ecranOLED.display();
}

void changerMenu() {
  if (menuState == 0) {  // Menu principal
    menuState = (selection == 0) ? 1 : 2;
  } else if (menuState == 1) {  // Sous-menu Config
    if (selection == 1) {
      menuState = 0;  // Retour au menu principal
    } else if (selection == 0) {
      menuState = 5;  // Aller au réglage du potentiomètre
    }
  } else if (menuState == 2) {  // Sous-menu Mesure
    if (selection == 2) {
      menuState = 0;  // Retour au menu principal
    } else if (selection == 1) {
      menuState = 3;  // Aller au menu du capteur Flex
    } else if (selection == 0) {
      menuState = 4;  // Aller au menu du capteur Graphite
    }
  } else if (menuState == 3) {  // Menu du capteur Flex
    if (selection == 1) {  // Si "Retour" est sélectionné
      menuState = 2;  // Retour au menu "Mesure"
    } else {
      afficherValeurFlex();
    }
  } else if (menuState == 4) {  // Menu du capteur Graphite
    if (selection == 1) {  // Si "Retour" est sélectionné
      menuState = 2;  // Retour au menu "Mesure"
    } else {
      afficherValeurGraphite(resistanceWB);
    }
  } else if (menuState == 5) {  // Menu de réglage du potentiomètre
    menuState = 1;  // Retour au menu "Config" après validation
  }

  selection = 0;  // Réinitialiser la sélection
  afficherMenu();
}

void doEncoder() {

  if (menuState == 5) {  // Si on est dans "Régler Pot."
    if (selection == 0) {  // Modification de la valeur du potentiomètre
      if (digitalRead(encoder0PinA) == HIGH && digitalRead(encoder0PinB) == HIGH) {
        potValue = min(potValue + 10, 255);
      } else if (digitalRead(encoder0PinA) == HIGH && digitalRead(encoder0PinB) == LOW) {
        potValue = max(potValue - 10, 0);
      }
    } else {  // Navigation sur "OK"
      selection = (selection == 0) ? 1 : 0;
    }
    encoderChanged = true;
  } else {  // Navigation normale dans les menus
    int maxOptions = (menuState == 1 || menuState == 2) ? 3 : 2;
    if (digitalRead(encoder0PinA) == HIGH && digitalRead(encoder0PinB) == HIGH) {
      selection = (selection + 1) % maxOptions;
    } else if (digitalRead(encoder0PinA) == HIGH && digitalRead(encoder0PinB) == LOW) {
      selection = (selection - 1 + maxOptions) % maxOptions;
    }
    encoderChanged = true;
  }

  encoderChanged = true;
}

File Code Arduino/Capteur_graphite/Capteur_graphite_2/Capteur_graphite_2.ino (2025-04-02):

// Définition des pins
#define encoder0PinA  2  // CLK Output A
#define encoder0PinB  4  // DT Output B
#define Switch 5  // Bouton de l'encodeur

#include <Adafruit_SSD1306.h>

#define OLED_WIDTH 128
#define OLED_HEIGHT 64
#define OLED_RESET -1
#define OLED_I2C_ADDR 0x3C

Adafruit_SSD1306 ecranOLED(OLED_WIDTH, OLED_HEIGHT, &Wire, OLED_RESET);

// Variables globales
volatile int encoder0Pos = 0;
volatile bool encoderChanged = false;

//Bluetooth
#include <SoftwareSerial.h>
#define RX 8  // Broche RX du module Bluetooth
#define TX 7  // Broche TX du module Bluetooth
#define ADC A0  // Broche de lecture de la résistance
SoftwareSerial bluetooth(TX, RX);  // Création d'un port série logiciel

//FlexSensor
#define FLEX_SENSOR_PIN A1
#include <Wire.h>
#include <Adafruit_GFX.h>

int menuState = 0;  // 0 = Menu principal, 1 = Config, 2 = Mesure
int selection = 0;  // Position de sélection (0, 1 ou 2)

bool lastButtonState = HIGH;
bool buttonPressed = false;

void setup() {
  Serial.begin(9600);

  pinMode(encoder0PinA, INPUT);
  pinMode(encoder0PinB, INPUT);
  pinMode(Switch, INPUT_PULLUP);

  attachInterrupt(digitalPinToInterrupt(encoder0PinA), doEncoder, CHANGE);

  if (!ecranOLED.begin(SSD1306_SWITCHCAPVCC, OLED_I2C_ADDR)) {
    while (1);
  }

  afficherMenu();

  //Flexsensor
  if (!ecranOLED.begin(SSD1306_SWITCHCAPVCC, 0x3C)) { // Adresse I2C : 0x3C
        Serial.println("Échec de l'initialisation de l'écran OLED");
        for (;;);
    }

  // Ecran OLED 
  if(!ecranOLED.begin(SSD1306_SWITCHCAPVCC, adresseI2CecranOLED))
    while(1);
  // Arrêt du programme (boucle infinie) si échec d'initialisation
  ecranOLED.clearDisplay();
  ecranOLED.setTextSize(3);                   // Taille des caractères (2:1)
  ecranOLED.setTextColor(SSD1306_WHITE); 
  ecranOLED.println("Config");
  ecranOLED.println("Mesure");
  ecranOLED.display();
  
  //Bluetooth
  bluetooth.begin(9600);  // Communication avec le module Bluetooth
  Serial.println("Module Bluetooth prêt");                          // Transfert le buffer à l'écran
}

void loop() {
  if (encoderChanged) {
  //Rotatif
  if (encoderChanged) {  // Si la valeur de l'encodeur a changé
    encoderChanged = false;
    afficherMenu();
    afficherMenu();  // Afficher la nouvelle valeur
  }

  detecterAppuiBouton();
}

void detecterAppuiBouton() {
  bool buttonState = digitalRead(Switch);

  if (buttonState == LOW && lastButtonState == HIGH) {
    delay(50);
    if (digitalRead(Switch) == LOW) {
      buttonPressed = true;
    }
  }

  if (buttonState == HIGH && lastButtonState == LOW) {
    if (buttonPressed) {
      changerMenu();
      buttonPressed = false;
    }
  }

  lastButtonState = buttonState;
}
  //Bluetooth
  int valeurBrute = analogRead(ADC);
    float tension = (valeurBrute / 1024.0) * 5.0;  // Conversion en tension (0-5V)
    Serial.print("Tension mesurée : ");
    Serial.print(tension);
    Serial.println(" V");

    //bluetooth.print("Tension: ");
    bluetooth.print(tension);
    //bluetooth.println(" V");

    //FlexSensor
    int VFlexbrute = analogRead(FLEX_SENSOR_PIN);
    float VFlexSensor = (VFlexbrute / 1024.0) * 5.0; // Conversion en tension

    Serial.print("Valeur brute : ");
    Serial.print(VFlexbrute);
    Serial.print(" | Tension : ");
    Serial.print(VFlexSensor);
    Serial.println(" V");

    delay(1000);  // Envoi toutes les secondes
}


void afficherMenu() {
  ecranOLED.clearDisplay();
  ecranOLED.setTextSize(2);

  if (menuState == 0) {  // Menu principal
    afficherOption("Config", 0);
    afficherOption("Mesure", 1);
  } else if (menuState == 1) {  // Sous-menu "Config"
    afficherOption("Option A", 0);
    afficherOption("Option B", 1);
    afficherOption("Retour", 2);
  } else if (menuState == 2) {  // Sous-menu "Mesure"
    afficherOption("Graphite", 0);
    afficherOption("Flex", 1);
    afficherOption("Retour", 2);
  }

  ecranOLED.display();
}

void afficherOption(const char *texte, int position) {
  if (selection % 3 == position) {
    ecranOLED.setTextColor(SSD1306_BLACK, SSD1306_WHITE);
  } else {
    ecranOLED.setTextColor(SSD1306_WHITE, SSD1306_BLACK);
  }
  ecranOLED.setCursor(20, 10 + (position * 20));
  ecranOLED.println(texte);
}

void changerMenu() {
  if (menuState == 0) {  // Menu principal
    menuState = (selection == 0) ? 1 : 2;
  } else {  // Sous-menus
    if (selection == 2) {
      menuState = 0;  // Retour au menu principal
    }
  }

  selection = 0;  // Réinitialiser la sélection
  afficherMenu();
}

void doEncoder() {
  if (digitalRead(encoder0PinA) == HIGH && digitalRead(encoder0PinB) == HIGH) {
    selection = (selection + 1) % 3;
  } else if (digitalRead(encoder0PinA) == HIGH && digitalRead(encoder0PinB) == LOW) {
    selection = (selection - 1 + 3) % 3;
  }

  encoderChanged = true;
}

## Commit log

2025-03-27 new files
    [1 3 OLED ICC .STEP, FlexSensor.SLDASM, SSD1306_OLED_Display(128x64).step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]
2025-05-17 banc de test
2025-05-18 fautes de frappe
2025-05-29 appli_annotée
    [Mesures.xlsx]
